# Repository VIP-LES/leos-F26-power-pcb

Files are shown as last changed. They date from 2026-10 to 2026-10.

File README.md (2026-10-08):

# LEOS F26 Power PCB

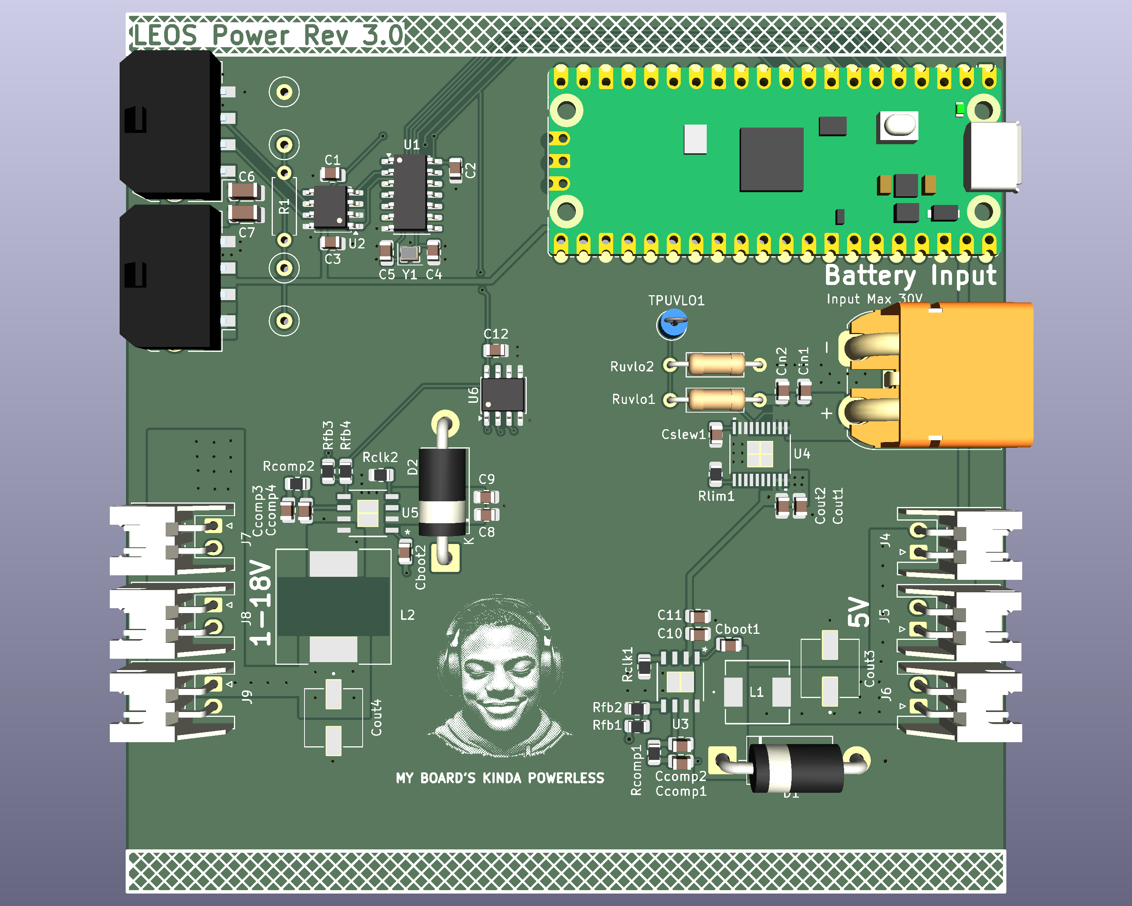
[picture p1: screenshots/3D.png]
3D render of the LEOS F26 Power PCB


This repository contains the KiCad design files for the LEOS power board made fall 2026. The board is designed to accept power from a 6S LiPo battery, provide input protection, and generate adjustable DC output for other LEOS components. This board also includes the base elements from the template board.

The design uses a Texas Instruments TPS16630 eFuse for input protection and two TPS54540B buck converters for voltage regulation. A Raspberry Pi Pico controls the output voltage through the MCP41100 SPI digital potentiometer in one of the buck converter's feedback network. 

The target output ranges are 5V at up to 5A and 1-18V at up to 5A. 

# Board Overview
The power board has three main functions:
Input protection: A TPS16630 eFuse provides adjustable undervoltage lockout, overvoltage protection, current limiting, and controlled startup.
DC-DC conversion: Two TPS54540B switching buck converters step down the battery voltage to both a fixed and adjustable output voltage.
Digital control: A Raspberry Pi Pico communicates with an MCP41100 digital potentiometer over SPI to adjust one of the buck converters' feedback resistance.

# Electrical design targets
Input source: 6S LiPo battery
Nominal input voltage: 22.2V
Fully charged battery voltage: 25.2V
Input undervoltage cutoff: Approximately 19-19.5V
Output voltage: 5V and approximately 1-18V adjustable 
Maximum output current: 5A
Buck converter: TPS54540B
eFuse: TPS16630
Digital potentiometer: MCP41100T-I/SN
Control interface: SPI from Raspberry Pi Pico

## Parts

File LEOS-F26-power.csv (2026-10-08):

Reference | Value | Qty | MPN | Digikey | Description | Manufacturer
A1 | RaspberryPi Pico | 1 | PIM724 | 1778-PIM724-ND | Pimoroni Pico Plus 2 | Pimoroni
C-1,C-2,C-3,C-4,C_1,C_2,C_3,C_4 | 4.7uF | 8 | CL21A475KBQNNNE | 1276-1248-1-ND | Unpolarized capacitor | Samsung Electro-Mechanics
C-5,C-9,C1,C2,C3,Cin1,C_5 | 0.1u | 7 | CL21B104KBCNNNC | 1276-1003-1-ND | 0.1uF 50V X7R 0805 | Samsung Electro-Mechanics
C-6 | 620p | 1 | GRM2165C1H621JA01D | 490-1618-1-ND | Unpolarized capacitor | Murata Electronics
C-7,C_7 | 6.8p | 2 | C0805C689C3HACAUTO | 399-C0805C689C3HACAUTOCT-ND | Unpolarized capacitor | KEMET
C-8,C_8 | 47u | 2 | A768EB476M1VLAE042 | 399-A768EB476M1VLAE042CT-ND | Unpolarized capacitor | KEMET
C4,C5 | 10p | 2 | CL21C100CBANNNC | 1276-2561-1-ND | 10pF 50V C0G/NP0 0805 | Samsung Electro-Mechanics
C6,C7 | 22u | 2 | CL31A226MOCLNNC | 1276-2728-1-ND | 22uF 10V X7R 1206 | Samsung Electro-Mechanics
CdVdt1,C_6 | 4.7n | 2 | C0805C472J3GEC7210 | 399-C0805C472J3GEC7210CT-ND | Unpolarized capacitor | KEMET
Cin2,Cout1,Cout2 | 10uF | 3 | GRM21BR61E106MA73L | 490-10748-1-ND | Unpolarized capacitor | Murata Electronics
D-1,D_1 | 60V 20A | 2 | SB2060 | 1655-SB2060CT-ND | Schottky diode | SMC Diode Solutions
J1,J2 | MicroFit_1x4 | 2 | 0436500409 | WM1882CT-ND | Molex MicroFit3.0 1x4 Bus Connector | Molex
J3 | Power Input | 1 |  |  | Generic connector, single row, 01x02, script generated | JST
J4,J5,J6 | 5V | 3 | S2B-XH-A | 455-S2B-XH-A-ND | Generic connector, single row, 01x02, script generated | JST
J7,J8,J9 | 1-18V | 3 | S2B-XH-A | 455-S2B-XH-A-ND | Generic connector, single row, 01x02, script generated | JST
L-1 | 10uH | 1 | SRR1280-100M | SRR1280-100MCT-ND | Inductor | Bourns Inc.
L_1 | 4.7uH | 1 | SRP7028A-4R7M | SRP7028A-4R7MCT-ND | Inductor | Bourns Inc.
R-1 | 390k | 1 | RMCF0805FT390K | RMCF0805FT390KCT-ND | Resistor | Stackpole Electronics Inc
R-2 | 56.2k | 1 | RMCF0805FT56K2 | RMCF0805FT56K2CT-ND | Resistor | Stackpole Electronics Inc
R-3 | 1.1k | 1 | RMCF0805FT1K10 | RMCF0805FT1K10CT-ND | Resistor | Stackpole Electronics Inc
R-4 | 26.1k | 1 | RMCF0805FT26K1 | RMCF0805FT26K1CT-ND | RES 26.1K OHM 1% 1/8W 0805 | Stackpole Electronics Inc
R.1 | 160k | 1 | MFR-25FTE52-160K | 13-MFR-25FTE52-160KCT-ND | Resistor | YAGEO
R.2 | 10k | 1 | MFR-25FRF52-10K | 13-MFR-25FRF52-10KCT-ND | Resistor | YAGEO
R_1 | 147k | 1 | RMCF0805FT147K | RMCF0805FT147KCT-ND | Resistor | Stackpole Electronics Inc
R_2 | 23.7k | 1 | RMCF0805FT23K7 | 738-RMCF0805FT23K7CT-ND | Resistor | Stackpole Electronics Inc
R_3 | 60.4k | 1 | RMCF0805FT60K4 | RMCF0805FT60K4CT-ND | Resistor | Stackpole Electronics Inc
R_4 | 11.5k | 1 | RMCF0805FT11K5 | RMCF0805FT11K5CT-ND | Resistor | Stackpole Electronics Inc
R_ILIM1 | 3.0k | 1 | RMCF0805FT3K00 | RMCF0805FT3K00CT-ND | Resistor | Stackpole Electronics Inc
U1 | MCP2518FD | 1 | MCP2518FDT-E/SL | MCP2518FDT-E/SLCT-ND | External CAN FD Controller with SPI Interface | Microchip
U2 | MCP2562FD | 1 | MCP2562FDT-H/SN | MCP2562FDT-E/SNCT-ND | High-Speed CAN Flexible Data Rate Transceiver | Microchip
U3,U5 | TPS54540BDDA | 2 | TPS54540BDDA | 296-TPS54540BDDA-ND |  | Texas Instruments
U4 | TPS16630PWPR | 1 | TPS16630PWPT | 296-TPS16630PWPTCT-ND |  | Texas Instruments
U6 | MCP41100T-I/SN | 1 | MCP41100T-I/SN | MCP41100T-I/SNCT-ND |  | Microchip Technology
Y1 | 40 MHz | 1 | ECS-400-10-37B2-CKY-TR | 50-ECS-400-10-37B2-CKY-TRCT-ND | 40 MHz ±10ppm Crystal 10pF 40 Ohms SMD2016 | ECS Inc,

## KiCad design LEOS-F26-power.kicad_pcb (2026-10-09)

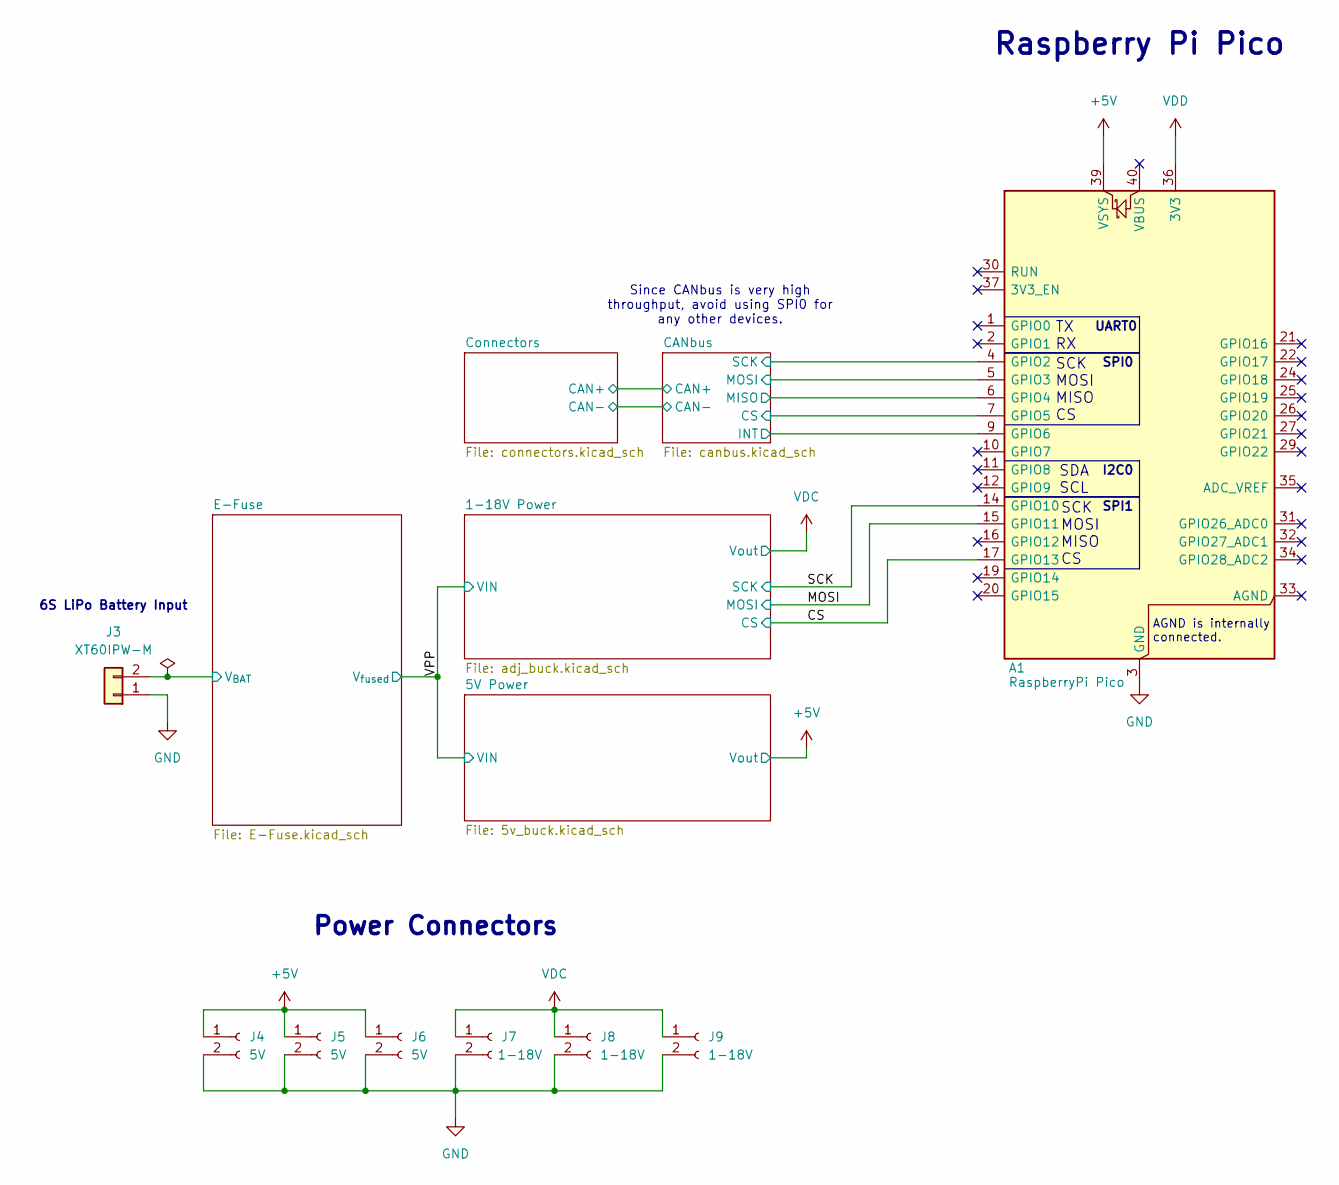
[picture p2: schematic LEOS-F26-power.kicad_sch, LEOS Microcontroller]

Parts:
A1: RaspberryPi Pico; RaspberryPi_Pico_Common_Unspecified; MPN PIM724; Digikey 1778-PIM724-ND
J3: XT60IPW-M; AMASS_XT60IPW-M_1x03_P7.20mm_Horizontal
J4, J5, J6: 5V; JST_XH_S2B-XH-A_1x02_P2.50mm_Horizontal; MPN S2B-XH-A; Digikey 455-S2B-XH-A-ND
J7, J8, J9: 1-18V; JST_XH_S2B-XH-A_1x02_P2.50mm_Horizontal; MPN S2B-XH-A; Digikey 455-S2B-XH-A-ND

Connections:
+5V: A1.39 (VSYS), J4.1, J5.1, J6.1; also elsewhere on the board
/CANbus/CS: A1.7 (GPIO5); also elsewhere on the board
/CANbus/INT: A1.9 (GPIO6); also elsewhere on the board
/CANbus/MISO: A1.6 (GPIO4); also elsewhere on the board
/CANbus/MOSI: A1.5 (GPIO3); also elsewhere on the board
/CANbus/SCK: A1.4 (GPIO2); also elsewhere on the board
/CS: A1.17 (GPIO13); also elsewhere on the board
/E-Fuse/V_{BAT}: J3.2; also elsewhere on the board
/MOSI: A1.15 (GPIO11); also elsewhere on the board
/SCK: A1.14 (GPIO10); also elsewhere on the board
GND: A1.3 (GND), A1.8 (GND), A1.13 (GND), A1.18 (GND), A1.23 (GND), A1.28 (GND), A1.38 (GND), J3.1, J4.2, J5.2, J6.2, J7.2, J8.2, J9.2; also elsewhere on the board
VDC: J7.1, J8.1, J9.1; also elsewhere on the board
VDD: A1.36 (3V3); also elsewhere on the board

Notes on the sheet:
SPI1
Raspberry Pi Pico
SCK MOSI MISO CS
Power Connectors
Since CANbus is very high throughput, avoid using SPI0 for any other devices.
SPI0
SDA SCL
TX RX
6S LiPo Battery Input
UART0
I2C0
AGND is internally connected.

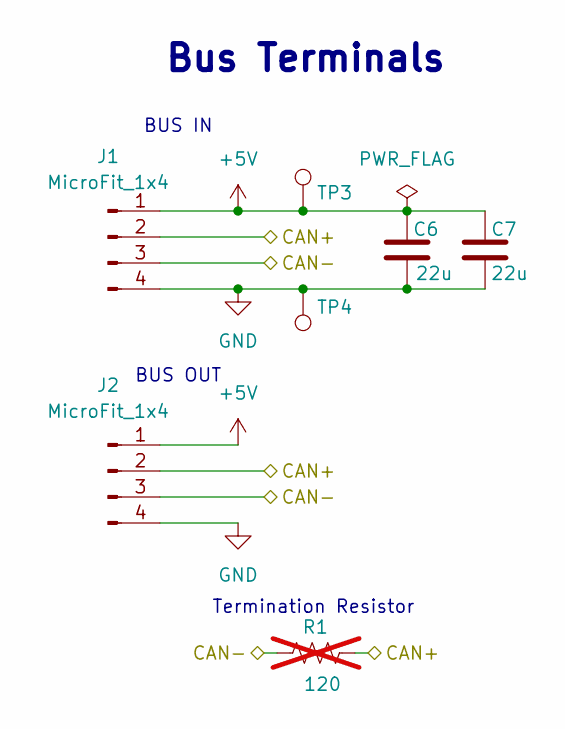
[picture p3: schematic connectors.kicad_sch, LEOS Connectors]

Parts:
C6, C7: 22u; C_1206_3216Metric; MPN CL31A226MOCLNNC; Digikey 1276-2728-1-ND
J1, J2: MicroFit_1x4; Molex_MicroFit3.0_43650-0410_1x04_Horizontal; MPN 0436500409; Digikey WM1882CT-ND
R1: 120; R_Axial_DIN0207_L6.3mm_D2.5mm_P7.62mm_Horizontal; MPN CF14JT120R; Digikey CF14JT120RCT-ND; not fitted
TP3: 5V Test Point; TestPoint_Loop_D2.60mm_Drill0.9mm_Beaded; MPN 5000; Digikey 36-5000-ND
TP4: GND Test Point; TestPoint_Loop_D2.60mm_Drill0.9mm_Beaded; MPN 5001; Digikey 36-5001-ND

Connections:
+5V: C6.1, C7.1, J1.1, J2.1, TP3.1 (1_1); also elsewhere on the board
/CANbus/CAN+: J1.2, J2.2, R1.2; also elsewhere on the board
/CANbus/CAN-: J1.3, J2.3, R1.1; also elsewhere on the board
GND: C6.2, C7.2, J1.4, J2.4, TP4.1 (1_1); also elsewhere on the board

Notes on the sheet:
BUS OUT
Bus Terminals
BUS IN
Termination Resistor

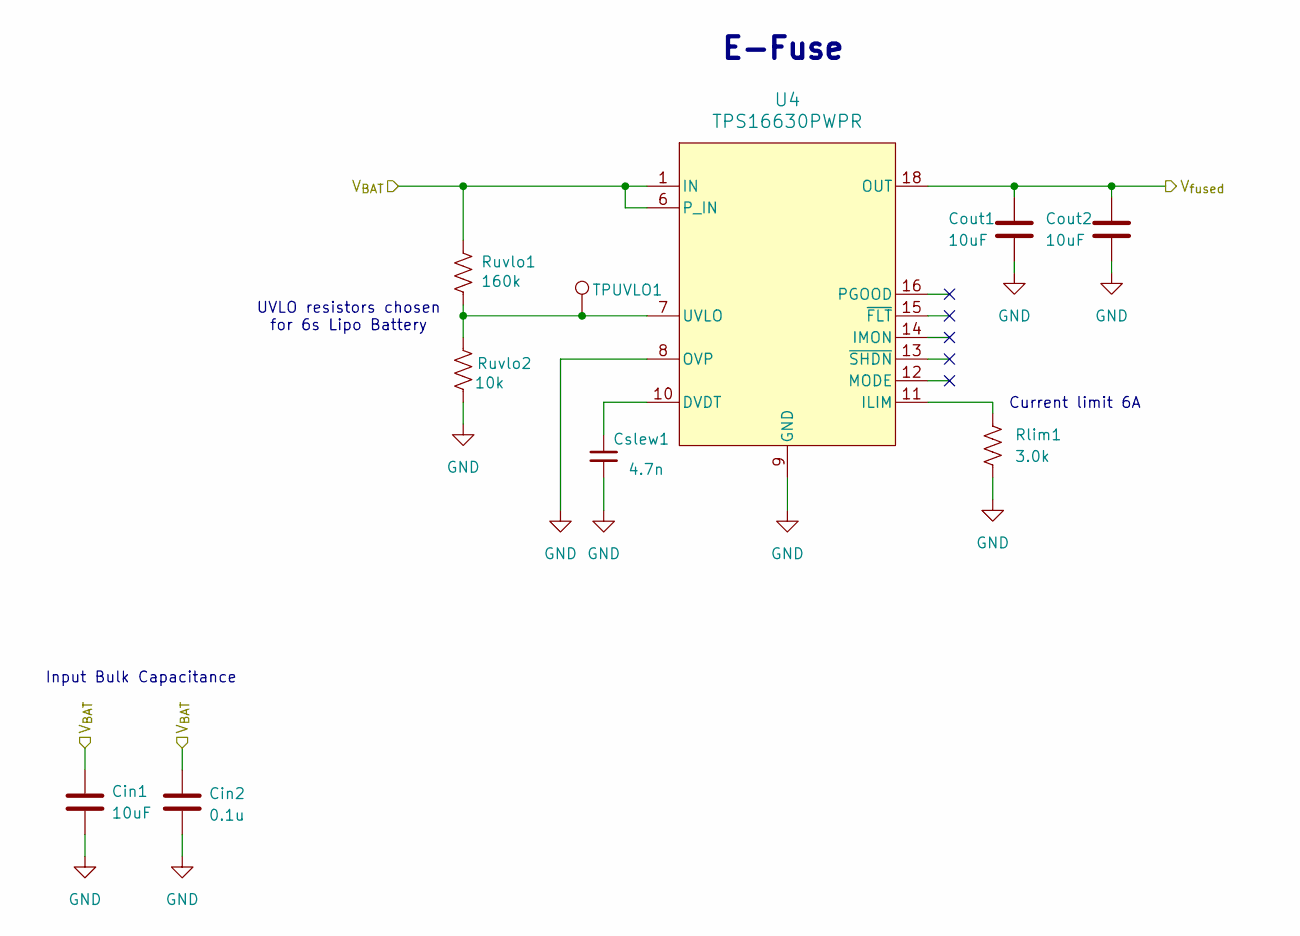
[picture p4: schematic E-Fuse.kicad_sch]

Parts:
Cin1: 10uF; C_0805_2012Metric; MPN GRM21BR61E106MA73L; Digikey 490-10748-1-ND
Cin2: 0.1u; C_0805_2012Metric; MPN CL21B104KBCNNNC; Digikey 1276-1003-1-ND
Cout1, Cout2: 10uF; C_0805_2012Metric; MPN GRM21BR61E106MA73L; Digikey 490-10748-1-ND
Cslew1: 4.7n; C_0805_2012Metric; MPN C0805C472J3GEC7210; Digikey 399-C0805C472J3GEC7210CT-ND
Rlim1: 3.0k; R_0805_2012Metric; MPN RMCF0805FT3K00; Digikey RMCF0805FT3K00CT-ND
Ruvlo1: 160k; R_Axial_DIN0207_L6.3mm_D2.5mm_P10.16mm_Horizontal; MPN MFR-25FTE52-160K; Digikey 13-MFR-25FTE52-160KCT-ND
Ruvlo2: 10k; R_Axial_DIN0207_L6.3mm_D2.5mm_P10.16mm_Horizontal; MPN MFR-25FRF52-10K; Digikey 13-MFR-25FRF52-10KCT-ND
TPUVLO1: TestPoint; TestPoint_Loop_D2.60mm_Drill0.9mm_Beaded
U4: TPS16630PWPR; HTSSOP20_PWP_TEX; MPN TPS16630PWPT; Digikey 296-TPS16630PWPTCT-ND

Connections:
/E-Fuse/V_{BAT}: Cin1.1, Cin2.1, Ruvlo1.1, U4.1 (IN), U4.2 (IN), U4.3 (IN), U4.6 (P_IN); also elsewhere on the board
/VPP: Cout1.1, Cout2.1, U4.18 (OUT), U4.19 (OUT), U4.20 (OUT); also elsewhere on the board
GND: Cin1.2, Cin2.2, Cout1.2, Cout2.2, Cslew1.2, Rlim1.2, Ruvlo2.2, U4.8 (OVP), U4.9 (GND), U4.21 (GND); also elsewhere on the board
unnamed: Cslew1.1, U4.10 (DVDT)
unnamed: Rlim1.1, U4.11 (ILIM)
unnamed: Ruvlo1.2, Ruvlo2.1, TPUVLO1.1 (1_1), U4.7 (UVLO)

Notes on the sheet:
UVLO resistors chosen for 6s Lipo Battery
Current limit 6A
Input Bulk Capacitance
E-Fuse

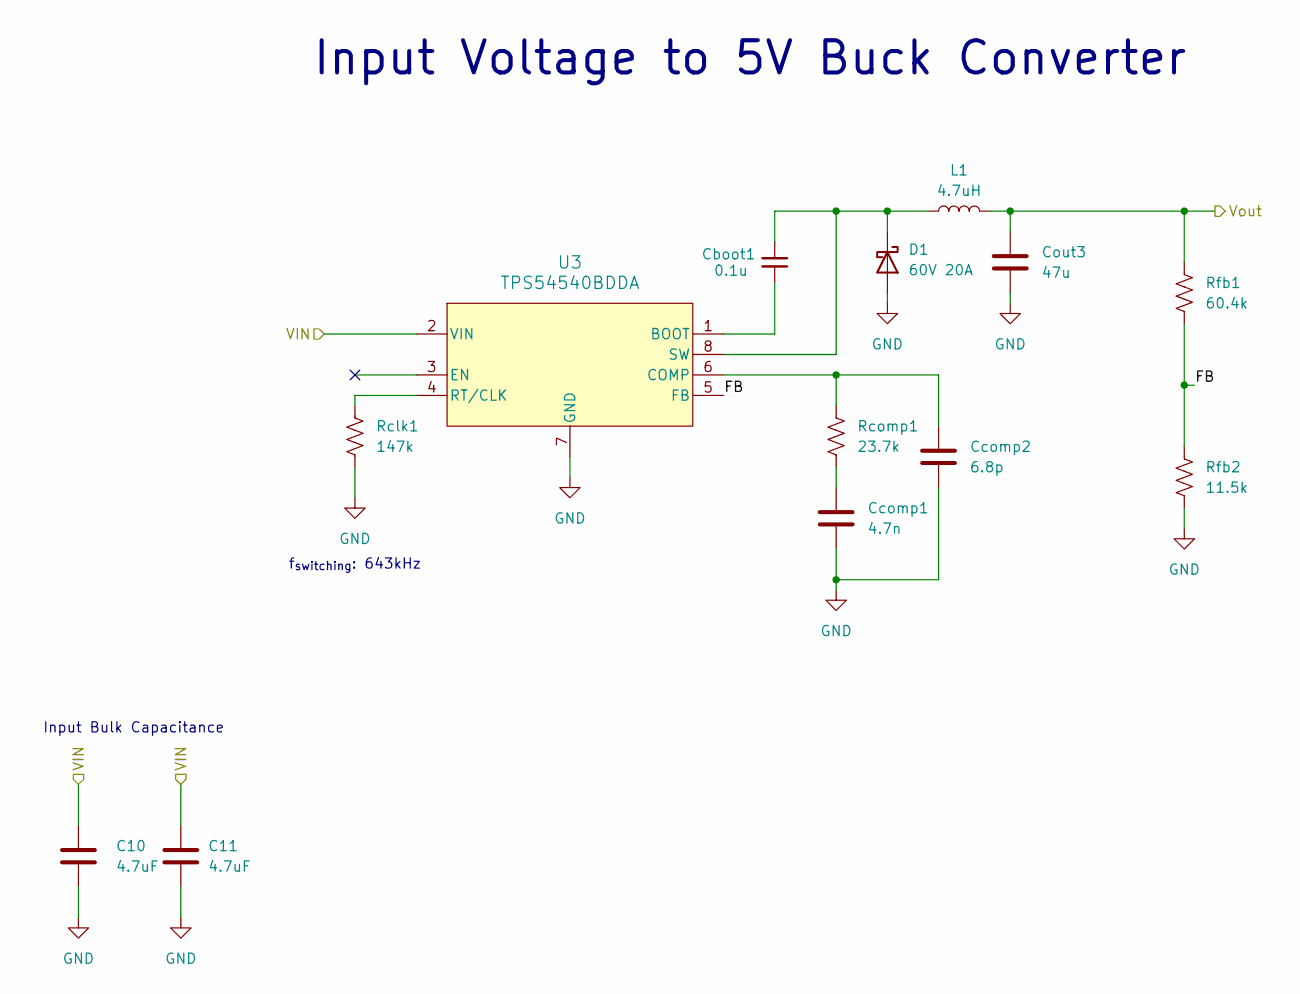
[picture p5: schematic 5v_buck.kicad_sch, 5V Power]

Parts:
C10, C11: 4.7uF; C_0805_2012Metric; MPN CL21A475KBQNNNE; Digikey 1276-1248-1-ND
Cboot1: 0.1u; C_0805_2012Metric; MPN CL21B104KBCNNNC; Digikey 1276-1003-1-ND
Ccomp1: 4.7n; C_0805_2012Metric; MPN C0805C472J3GEC7210; Digikey 399-C0805C472J3GEC7210CT-ND
Ccomp2: 6.8p; C_0805_2012Metric; MPN C0805C689C3HACAUTO; Digikey 399-C0805C689C3HACAUTOCT-ND
Cout3: 47u; CAPAE660X600N; MPN A768EB476M1VLAE042; Digikey 399-A768EB476M1VLAE042CT-ND
D1: 60V 20A; D_DO-201AD_P15.24mm_Horizontal; MPN SB2060; Digikey 1655-SB2060CT-ND
L1: 4.7uH; IND_SRP7028A-4R7M_BRN; MPN SRP7028A-4R7M; Digikey SRP7028A-4R7MCT-ND
Rclk1: 147k; R_0805_2012Metric; MPN RMCF0805FT147K; Digikey RMCF0805FT147KCT-ND
Rcomp1: 23.7k; R_0805_2012Metric; MPN RMCF0805FT23K7; Digikey 738-RMCF0805FT23K7CT-ND
Rfb1: 60.4k; R_0805_2012Metric; MPN RMCF0805FT60K4; Digikey RMCF0805FT60K4CT-ND
Rfb2: 11.5k; R_0805_2012Metric; MPN RMCF0805FT11K5; Digikey RMCF0805FT11K5CT-ND
U3: TPS54540BDDA; SO-POWERPAD8_DDA_TEX; MPN TPS54540BDDA; Digikey 296-TPS54540BDDA-ND

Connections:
+5V: Cout3.1, L1.2, Rfb1.1; also elsewhere on the board
/5V Power/FB: Rfb1.2, Rfb2.1, U3.5 (FB)
/VPP: C10.1, C11.1, U3.2 (VIN); also elsewhere on the board
GND: C10.2, C11.2, Ccomp1.2, Ccomp2.2, Cout3.2, D1.2 (A), Rclk1.2, Rfb2.2, U3.7 (GND), U3.EPAD (GND); also elsewhere on the board
unnamed: Ccomp1.1, Rcomp1.2
unnamed: Cboot1.2, D1.1 (K), L1.1, U3.8 (SW)
unnamed: Cboot1.1, U3.1 (BOOT)
unnamed: Ccomp2.1, Rcomp1.1, U3.6 (COMP)
unnamed: Rclk1.1, U3.4 (RT/CLK)

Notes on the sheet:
Input Bulk Capacitance
f_{switching}: 643kHz
Input Voltage to 5V Buck Converter

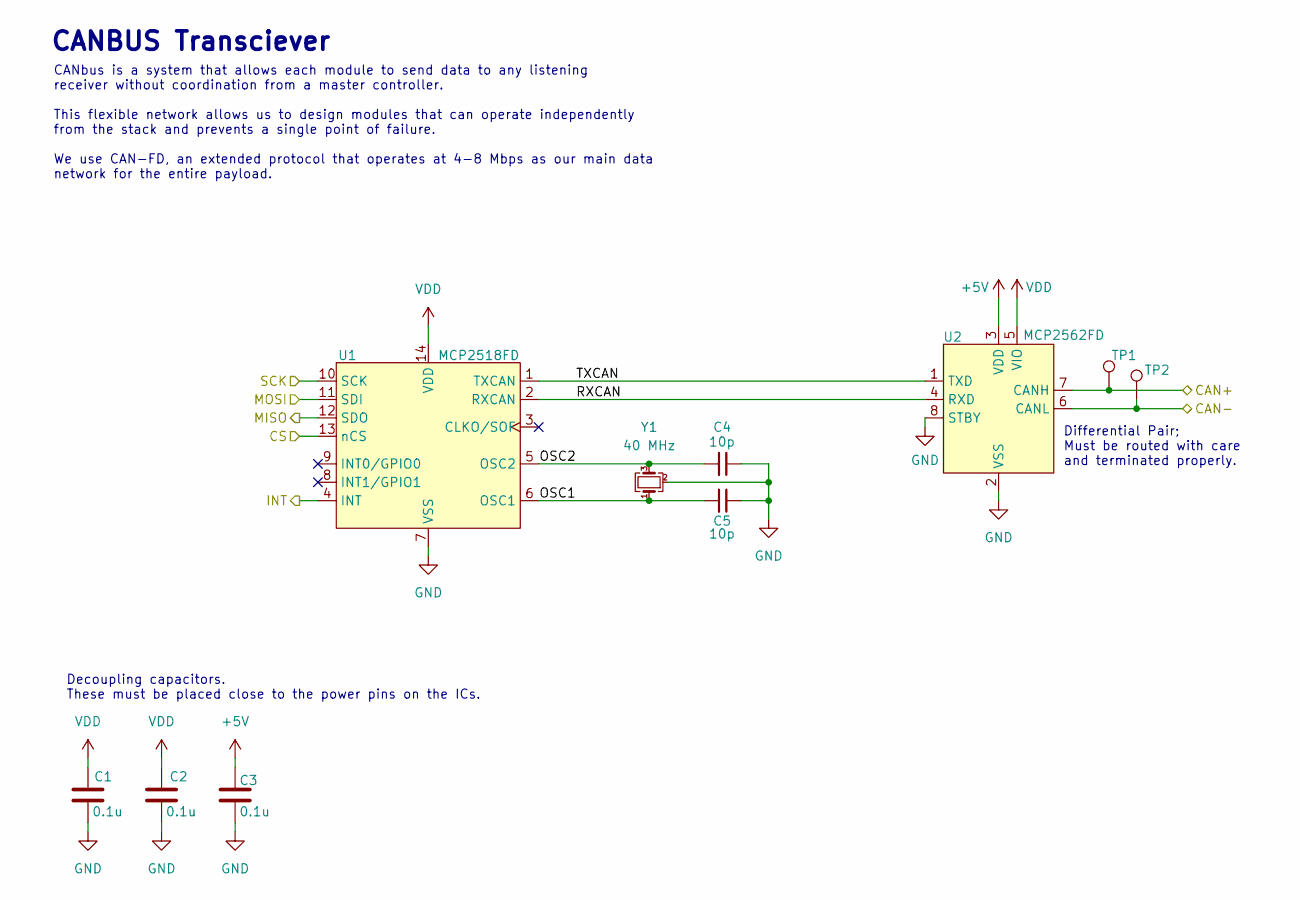
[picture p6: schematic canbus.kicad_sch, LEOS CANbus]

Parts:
C1, C2, C3: 0.1u; C_0805_2012Metric; MPN CL21B104KBCNNNC; Digikey 1276-1003-1-ND
C4, C5: 10p; C_0805_2012Metric; MPN CL21C100CBANNNC; Digikey 1276-2561-1-ND
TP1: CAN-H Test Point; TestPoint_Loop_D2.60mm_Drill0.9mm_Beaded; MPN 5004; Digikey 36-5004-ND
TP2: CAN-L Test Point; TestPoint_Loop_D2.60mm_Drill0.9mm_Beaded; MPN 5116; Digikey 36-5116-ND
U1: MCP2518FD; SOIC-14_3.9x8.7mm_P1.27mm; MPN MCP2518FDT-E/SL; LCSC C626758
U2: MCP2562FD; SOIC-8_3.9x4.9mm_P1.27mm; MPN MCP2562FDT-H/SN; LCSC C511335
Y1: 40 MHz; Crystal_SMD_2016-4Pin_2.0x1.6mm; MPN ECS-400-10-37B2-CKY-TR; Digikey 50-ECS-400-10-37B2-CKY-TRCT-ND

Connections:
+5V: C3.1, U2.3 (VDD); also elsewhere on the board
/CANbus/CAN+: TP1.1 (1_1), U2.7 (CANH); also elsewhere on the board
/CANbus/CAN-: TP2.1 (1_1), U2.6 (CANL); also elsewhere on the board
/CANbus/CS: U1.13 (nCS); also elsewhere on the board
/CANbus/INT: U1.4 (INT); also elsewhere on the board
/CANbus/MISO: U1.12 (SDO); also elsewhere on the board
/CANbus/MOSI: U1.11 (SDI); also elsewhere on the board
/CANbus/OSC1: C5.2, U1.6 (OSC1), Y1.1
/CANbus/OSC2: C4.2, U1.5 (OSC2), Y1.3
/CANbus/RXCAN: U1.2 (RXCAN), U2.4 (RXD)
/CANbus/SCK: U1.10 (SCK); also elsewhere on the board
/CANbus/TXCAN: U1.1 (TXCAN), U2.1 (TXD)
GND: C1.2, C2.2, C3.2, C4.1, C5.1, U1.7 (VSS), U2.2 (VSS), U2.8 (STBY), Y1.2 (G), Y1.4 (G); also elsewhere on the board
VDD: C1.1, C2.1, U1.14 (VDD), U2.5 (VIO); also elsewhere on the board

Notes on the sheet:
Differential Pair; Must be routed with care and terminated properly.
CANBUS Transciever
CANbus is a system that allows each module to send data to any listening receiver without coordination from a master controller. This flexible network allows us to design modules that can operate independently from the stack and prevents a single point of failure. We use CAN-FD, an extended protoco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
Decoupling capacitors. These must be placed close to the power pins on the ICs.

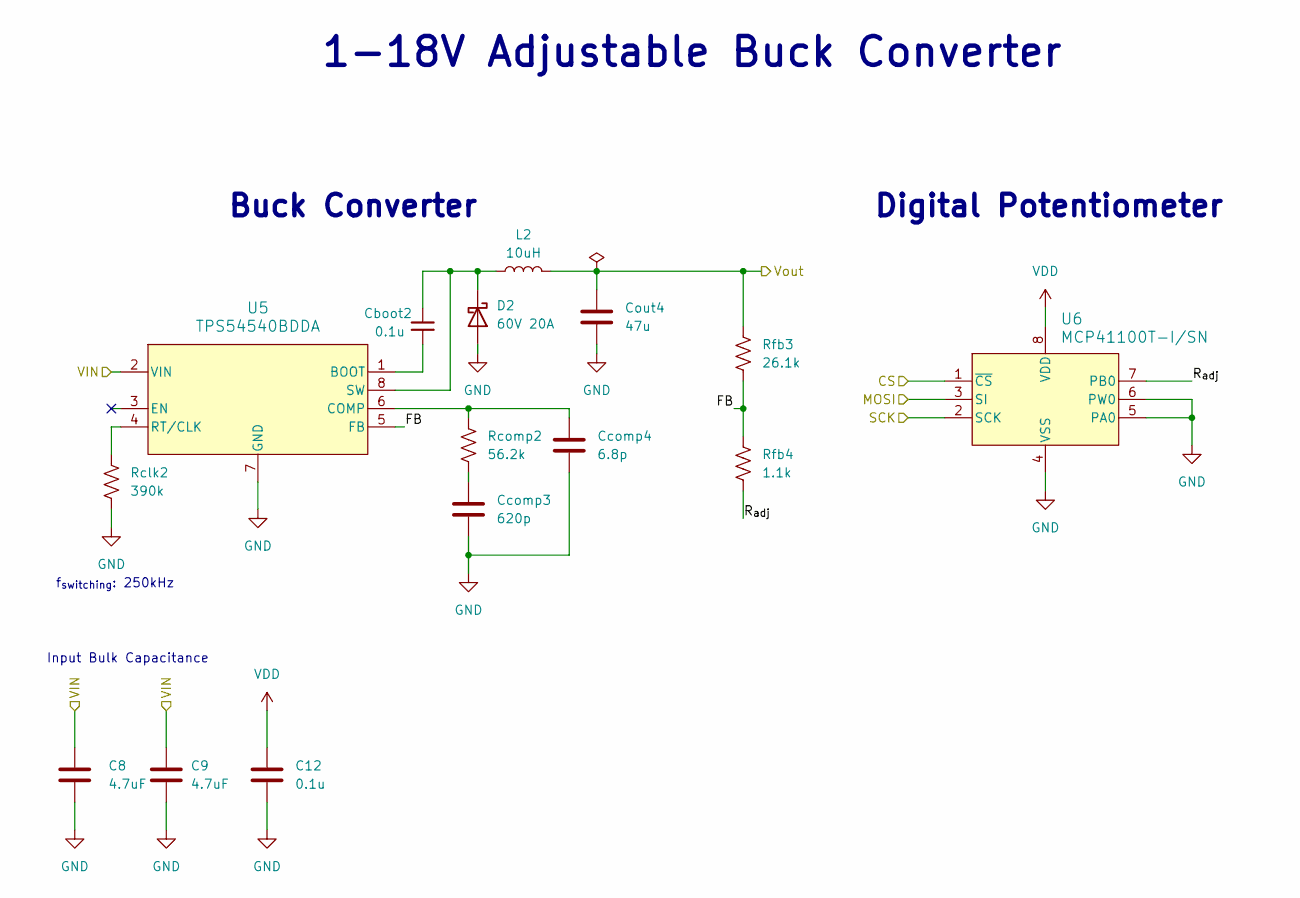
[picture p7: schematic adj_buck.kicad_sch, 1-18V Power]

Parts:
C8, C9: 4.7uF; C_0805_2012Metric; MPN CL21A475KBQNNNE; Digikey 1276-1248-1-ND
C12: 0.1u; C_0805_2012Metric; MPN CL21B104KBCNNNC; Digikey 1276-1003-1-ND
Cboot2: 0.1u; C_0805_2012Metric; MPN CL21B104KBCNNNC; Digikey 1276-1003-1-ND
Ccomp3: 620p; C_0805_2012Metric; MPN GRM2165C1H621JA01D; Digikey 490-1618-1-ND
Ccomp4: 6.8p; C_0805_2012Metric; MPN C0805C689C3HACAUTO; Digikey 399-C0805C689C3HACAUTOCT-ND
Cout4: 47u; CAPAE660X600N; MPN A768EB476M1VLAE042; Digikey 399-A768EB476M1VLAE042CT-ND
D2: 60V 20A; D_DO-201AD_P15.24mm_Horizontal; MPN SB2060; Digikey 1655-SB2060CT-ND
L2: 10uH; IND_BOURNS_SRR1280; MPN SRR1280-100M; Digikey SRR1280-100MCT-ND
Rclk2: 390k; R_0805_2012Metric; MPN RMCF0805FT390K; Digikey RMCF0805FT390KCT-ND
Rcomp2: 56.2k; R_0805_2012Metric; MPN RMCF0805FT56K2; Digikey RMCF0805FT56K2CT-ND
Rfb3: 26.1k; R_0805_2012Metric; MPN RMCF0805FT26K1; Digikey RMCF0805FT26K1CT-ND
Rfb4: 1.1k; R_0805_2012Metric; MPN RMCF0805FT1K10; Digikey RMCF0805FT1K10CT-ND
U5: TPS54540BDDA; SO-POWERPAD8_DDA_TEX; MPN TPS54540BDDA; Digikey 296-TPS54540BDDA-ND
U6: MCP41100T-I/SN; SOIC-8_3.9x4.9mm_P1.27mm; MPN MCP41100T-I/SN; Digikey MCP41100T-I/SNCT-ND

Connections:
/1-18V Power/FB: Rfb3.2, Rfb4.1, U5.5 (FB)
/1-18V Power/R_{adj}: Rfb4.2, U6.7 (PB0)
/CS: U6.1 (~CS); also elsewhere on the board
/MOSI: U6.3 (SI); also elsewhere on the board
/SCK: U6.2 (SCK); also elsewhere on the board
/VPP: C8.1, C9.1, U5.2 (VIN); also elsewhere on the board
GND: C8.2, C9.2, C12.2, Ccomp3.2, Ccomp4.2, Cout4.2, D2.2 (A), Rclk2.2, U5.7 (GND), U5.EPAD (GND), U6.4 (VSS), U6.5 (PA0), U6.6 (PW0); also elsewhere on the board
unnamed: Ccomp3.1, Rcomp2.2
unnamed: Cboot2.1, D2.1 (K), L2.1, U5.8 (SW)
unnamed: Cboot2.2, U5.1 (BOOT)
unnamed: Ccomp4.1, Rcomp2.1, U5.6 (COMP)
unnamed: Rclk2.1, U5.4 (RT/CLK)
VDC: Cout4.1, L2.2, Rfb3.1; also elsewhere on the board
VDD: C12.1, U6.8 (VDD); also elsewhere on the board

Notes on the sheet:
1-18V Adjustable Buck Converter
Digital Potentiometer
f_{switching}: 250kHz
Buck Converter
Input Bulk Capacitance

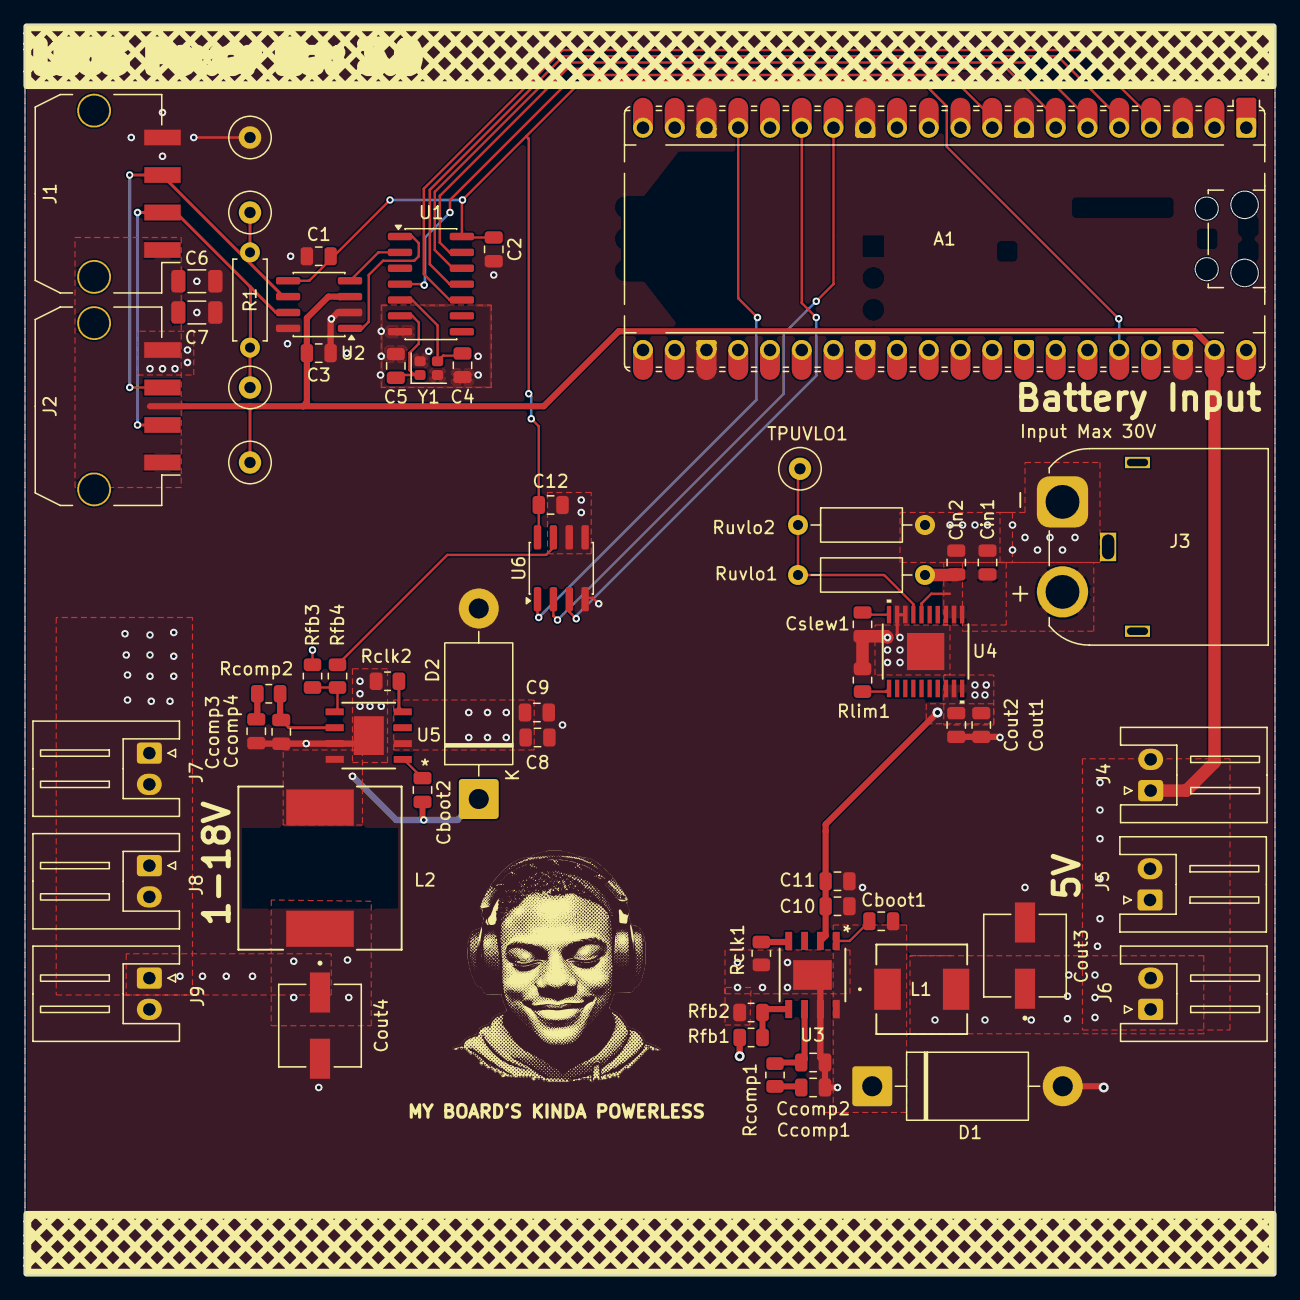
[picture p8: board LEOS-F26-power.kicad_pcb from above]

Board: 4 copper layers, 100.0 x 100.0 mm, 63 parts (0 on the bottom side), 36 nets.

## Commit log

2026-08-08 added buck converter
    [Buck Converter.kicad_sch, LEOS-F26-power.kicad_sch, canbus.kicad_sch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]
2026-09-10 Updates to the 5V buck converter
    [5V Power.kicad_sch, 9-12V Power.kicad_sch]
2026-09-10 updates to 5V buck converter
2026-09-17 efuse schematic
    [E-Fuse.kicad_sch]
2026-09-23 Added new potentiometer
    [5V Power.kicad_sch, 9-12V Power.kicad_sch, LEOS-F26-power.kicad_sch]
2026-09-23 updates to potentiometer
    [9-12V Power.kicad_sch, LEOS-F26-power.kicad_sch]
2026-09-23 updated values on buck
2026-09-24 added footprints
    [5V Power.kicad_sch, 9-12V Power.kicad_sch, E-Fuse.kicad_sch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]
2026-09-24 resistor part values
2026-09-24 resistor values
    [5V Power.kicad_sch, 9-12V Power.kicad_sch, E-Fuse.kicad_sch]
2026-09-27 Updates to BOM and power connection
2026-09-27 updates to BOM and power connections
    [5V Power.kicad_sch, 9-12V Power.kicad_sch, E-Fuse.kicad_sch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]
2026-09-28 updates to BOM and fixes for ERC
    [5V Power.kicad_sch, 9-12V Power.kicad_sch, E-Fuse.kicad_sch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]
2026-09-28 updates to efuse
    [E-Fuse.kicad_sch]
2026-09-30 updates to BOM and beginning of routing
    [5V Power.kicad_sch, 9-12V Power.kicad_sch, E-Fuse.kicad_sch]
2026-10-01 updates to BOM
    [5V Power.kicad_sch, 9-12V Power.kicad_sch, E-Fuse.kicad_sch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]
2026-10-01 switching frequency
    [9-12V Power.kicad_sch, E-Fuse.kicad_sch, connectors.kicad_sch]
2026-10-01 rearranging routing
    [E-Fuse.kicad_sch]
2026-10-01 efuse routing
    [LEOS-F26-power.kicad_pcb]
2026-10-01 efuse routing 2
    [LEOS-F26-power.kicad_pcb]
2026-10-01 hid test points from bom
    [5V Power.kicad_sch, 9-12V Power.kicad_sch, E-Fuse.kicad_sch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]
2026-10-01 buck converter routing
    [LEOS-F26-power.kicad_pcb]
2026-10-05 routing done
    [5V Power.kicad_sch, 9-12V Power.kicad_sch, E-Fuse.kicad_sch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]
2026-10-07 Change routing to include l2 power layer to rearrange buck layout
    [E-Fuse.kicad_sch, LEOS-F26-power.kicad_pcb]
2026-10-08 updates to routing and digital pot
    [9-12V Power.kicad_sch, LEOS-F26-power.csv, LEOS-F26-power.kicad_pcb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]
2026-10-08 Rename references, update symbols and schematic layout
    [5v_buck.kicad_sch, E-Fuse.kicad_sch, LEOS-F26-power.kicad_pcb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]
2026-10-08 Revised README for LEOS F26 Power PCB
2026-10-08 PLEASE SPEED I NEED THIS
    [LEOS-F26-power.kicad_pcb]
2026-10-08 Ignore KiCad lock files
2026-10-09 Remove unused schematic page
    [Buck Converter.kicad_sch]
2026-10-09 Move silkscreen references for TP and Cout
    [LEOS-F26-power.kicad_pcb]
